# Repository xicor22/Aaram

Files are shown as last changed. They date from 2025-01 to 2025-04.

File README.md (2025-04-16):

# Aaram  
PCB design for retro fitting old switch boards with new tech to control it remotely using ESP32-C6-Mini-N1.

## Features
1. Controls 4 loads using
  - 1 Triac 
      > Note: Triac circuit has added protection for the back EMF generated by inductive load like fan.
  - 3 Relays for controlling other resistive loads
      > Try not use heavy inductive load using relays. During testing, the MCU was bugging out when load was switched.
2. Input from switches.
      - To reduce rewiring the whole switch board, directly connect the rocker switch output terminal to the input provided on the board.
      - The FULL BRIDGE RECTIFIER rectifies the AC which is sent to the quad channel opto with a 100k resistor in series for current limiting. The output from the opto is read by the ESP.
3. Fuse holder in series with the AC input for overload protection. 
4. Varistor on all AC output terminals for protection from transient spikes.
5. Added support for IR receiver and transmitter.
6. Uses DHT22 for temperature and humidity sensor.
7. ESPHome Yaml config - [Link](https://github.com/xicor22/Aaram/blob/main/ESPHome_Template.yaml)
## Schematic
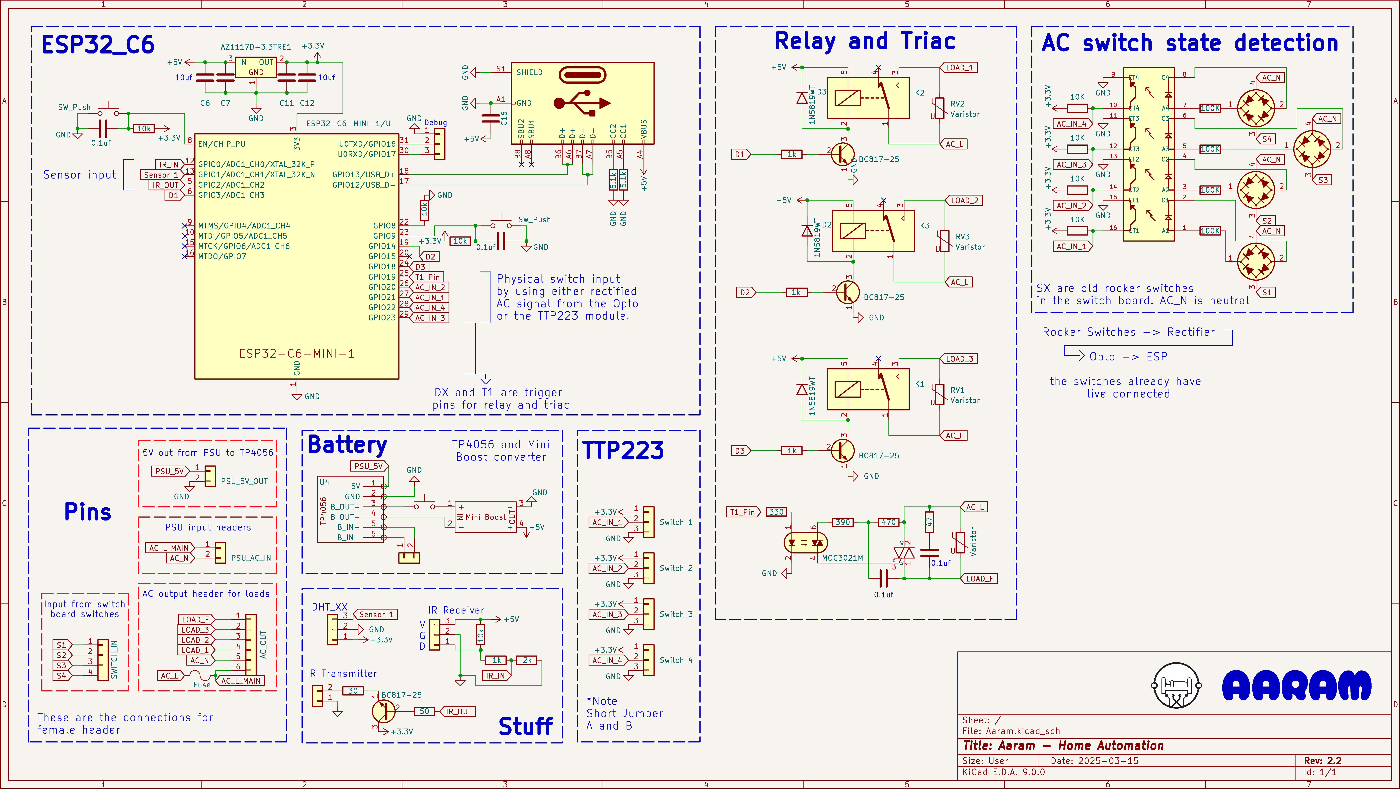
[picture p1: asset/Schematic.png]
Schematic


## Images
|View|Image|
|----|-----|
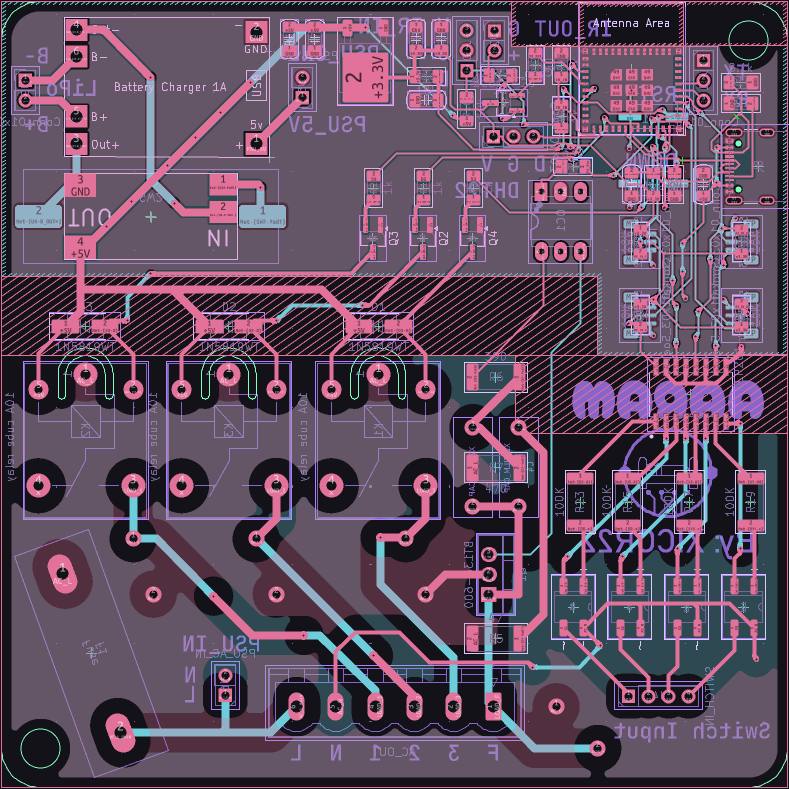
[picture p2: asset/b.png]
Both Layers
|Both Layers| |
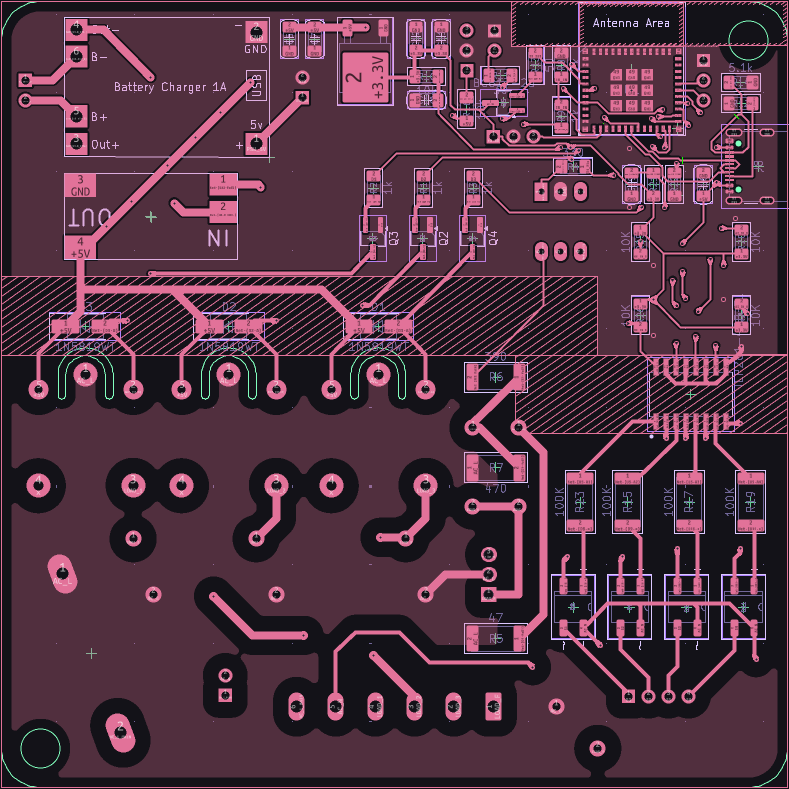
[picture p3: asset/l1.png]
Layer 1
|1<sup>st</sup> Layer| |
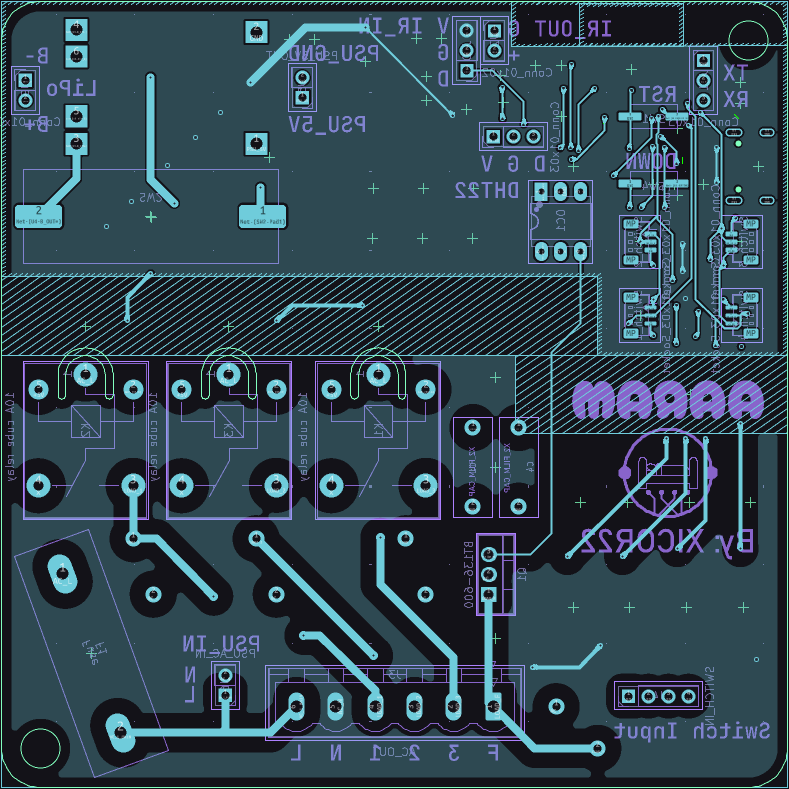
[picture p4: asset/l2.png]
Layer 2
|2<sup>nd</sup> Layer| |
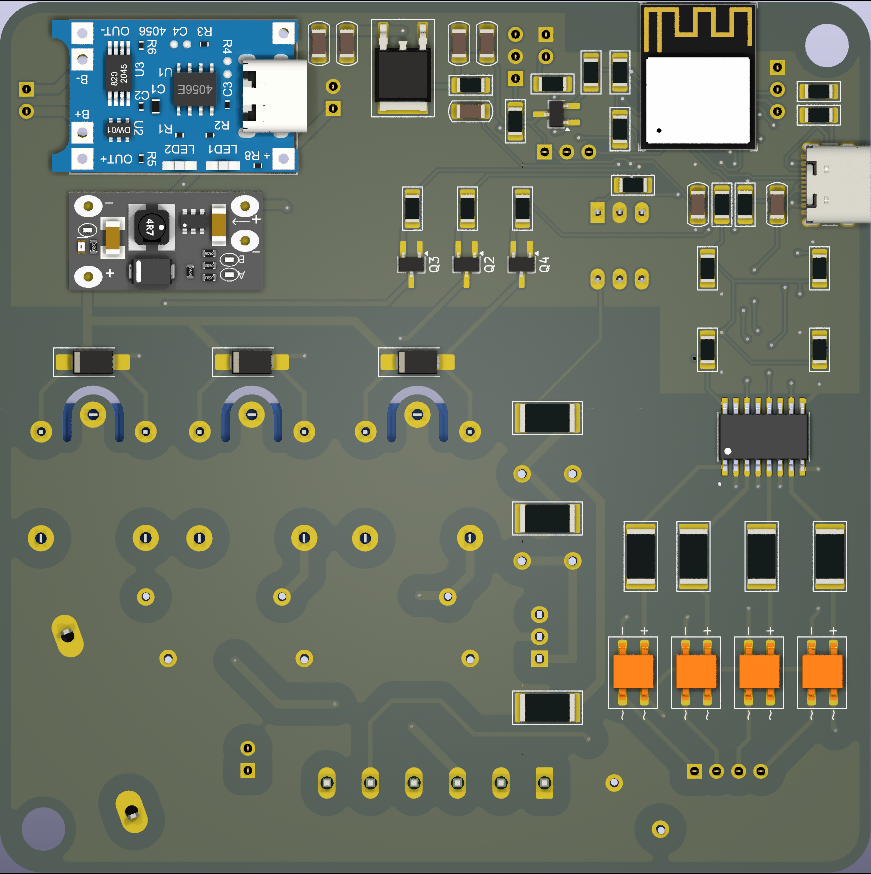
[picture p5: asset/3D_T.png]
3D Top View
|3D Top view| |
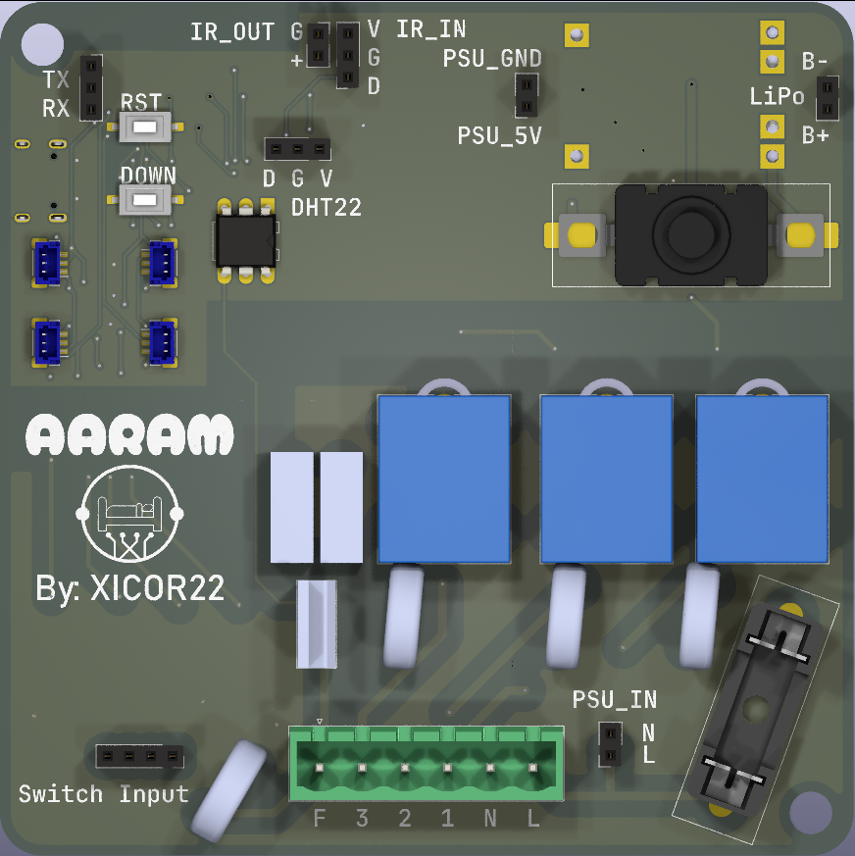
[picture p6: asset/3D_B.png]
3D Bottom View
|3D Bottom view| |

## To-Do
1. ~~Design 3D printables case for the PCB.~~ **Done**
2. Update ESPHOME yaml config.

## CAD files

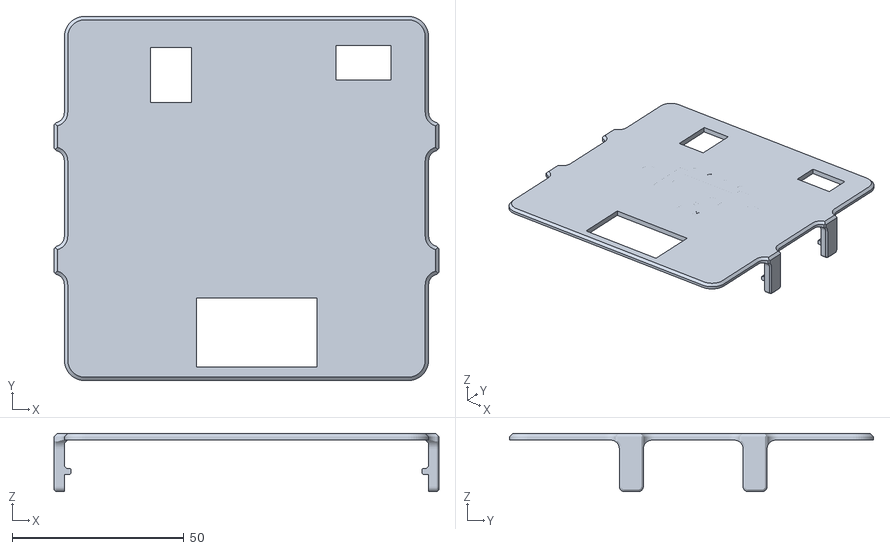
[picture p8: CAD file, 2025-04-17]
asset/Top.stl
112.0 x 106.0 x 17.0

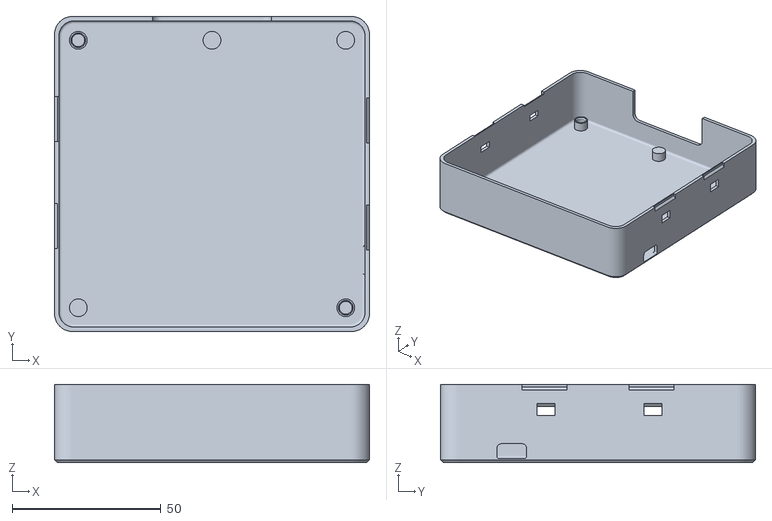
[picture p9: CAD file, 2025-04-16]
asset/Base.stl
106.0 x 106.0 x 26.4

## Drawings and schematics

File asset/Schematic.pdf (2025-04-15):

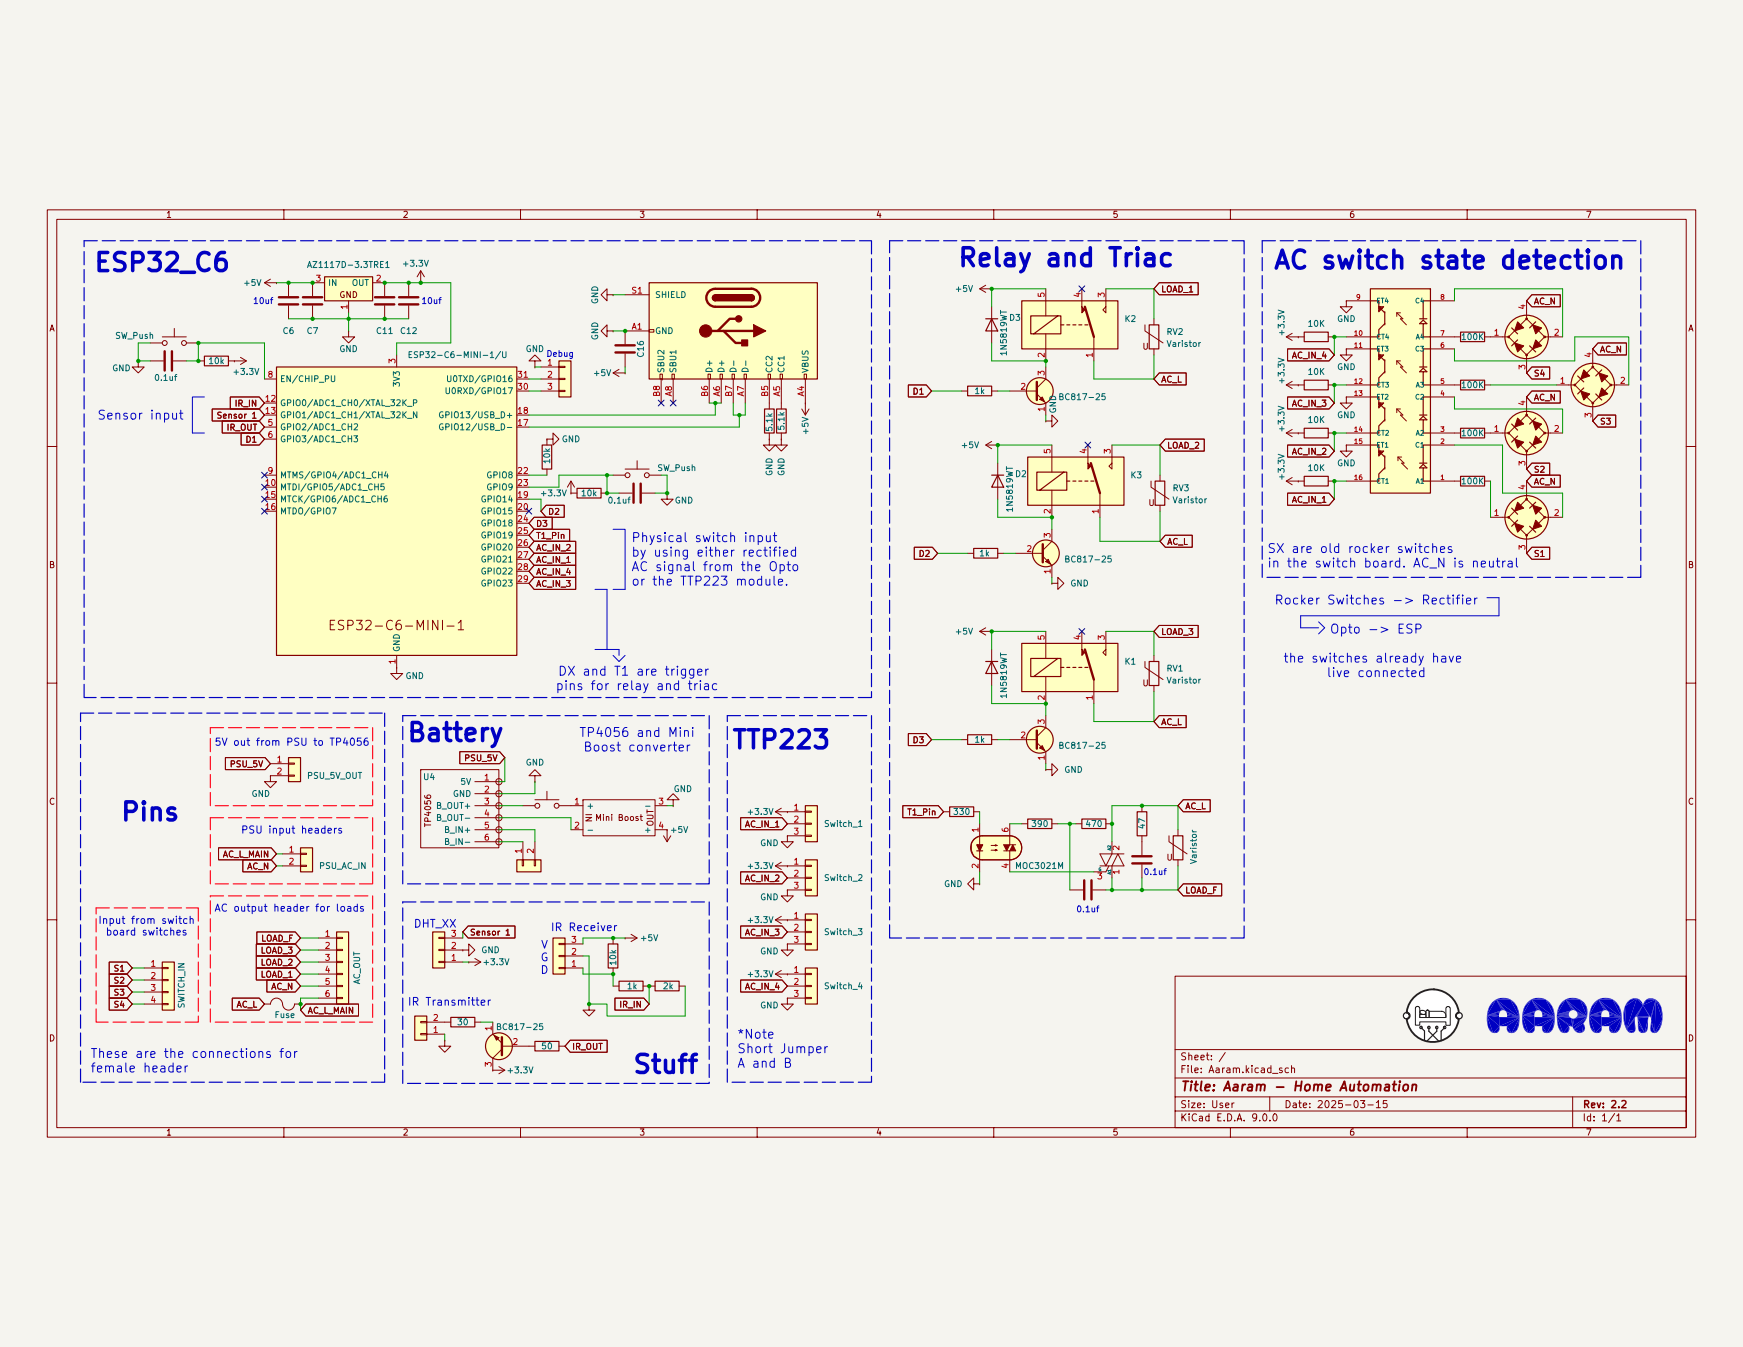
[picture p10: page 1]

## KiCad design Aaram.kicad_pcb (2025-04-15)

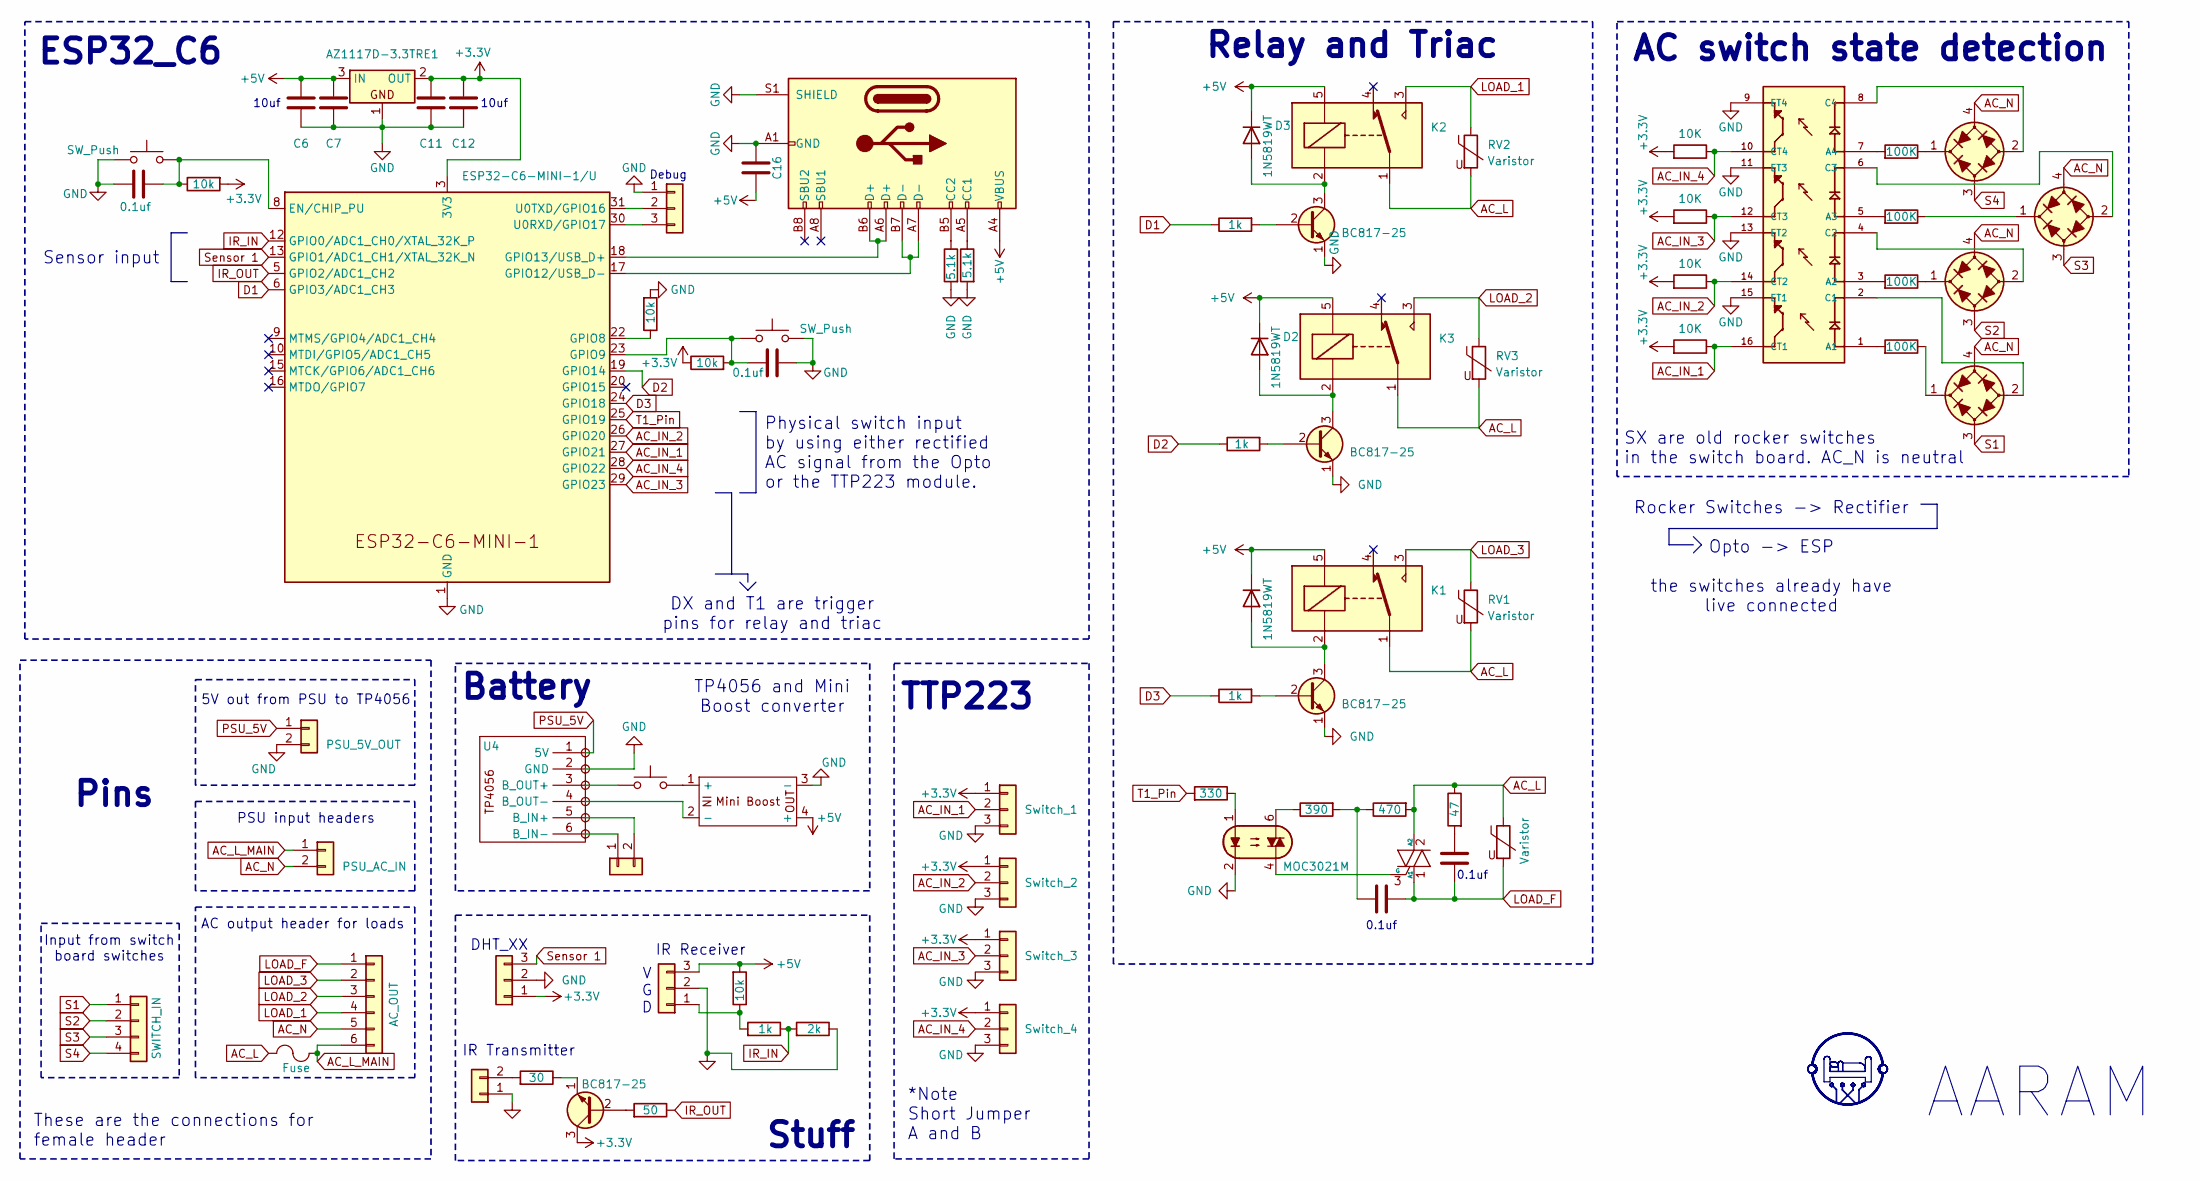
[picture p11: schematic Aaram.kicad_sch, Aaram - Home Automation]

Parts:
C1, C4: CP_Axial_L10.0mm_D4.5mm_P15.00mm; Axial_Capacitor_P10mm_W4.5mm
C6, C7, C11, C12: 10uf; C_1206_3216Metric_Pad1.42x1.75mm
C16: 1uf; C_1206_3216Metric_Pad1.42x1.75mm
C18, C19: 0.1uf; C_1206_3216Metric_Pad1.42x1.75mm
D1, D2, D3: 1N5819WT; D_SMA_Handsoldering
D8, D9, D10, D11: MB6S; Diode_Bridge_MBS
F1: Fuse; BLX-A
J1, J10, J11: Conn_01x03; PinSocket_1x03_P2.54mm_Vertical
J2, J9: Conn_01x02; PinSocket_1x02_P2.54mm_Vertical
J3: AC_OUT; 1x06_P5.00mm_D1.50mm
J4: SWITCH_IN; PinSocket_1x04_P2.54mm_Vertical
J5: PSU_5V_OUT; PinSocket_1x02_P2.54mm_Vertical
J6: PSU_AC_IN; PinSocket_1x02_P2.54mm_Vertical
J8: USB_C_Receptacle_USB2.0_16P; USB_C_Receptacle_GCT_USB4105-xx-A_16P_TopMnt_Horizontal
K1, K2, K3: 10A cube relay; Relay_SPDT_SANYOU_SRD_Series_Form_C
OC1: MOC3021M; DIP-6_W7.62mm_LongPads
Q1: BT136-600; TO-220-3_Vertical
Q2, Q3, Q4, Q5: BC817-25; TSOT-23_HandSoldering
R1, R2, R3, R9: 1k; R_1206_3216Metric_Pad1.42x1.75mm_HandSolder
R4: 330; R_1206_3216Metric_Pad1.42x1.75mm_HandSolder
R5: 47; R_2512_6332Metric_Pad1.52x3.35mm_HandSolder
R6: 390; R_2512_6332Metric_Pad1.52x3.35mm_HandSolder
R7: 470; R_2512_6332Metric_Pad1.52x3.35mm_HandSolder
R8: 2k; R_1206_3216Metric_Pad1.42x1.75mm_HandSolder
R10, R16, R21, R22: 10k; R_1206_3216Metric_Pad1.42x1.75mm_HandSolder
R11: 30; R_1206_3216Metric_Pad1.42x1.75mm_HandSolder
R12, R14: 5.1k; R_1206_3216Metric_Pad1.42x1.75mm_HandSolder
R13: 50; R_1206_3216Metric_Pad1.42x1.75mm_HandSolder
R15, R17, R19, R23: 100K; R_2512_6332Metric_Pad1.52x3.35mm_HandSolder
R20, R25, R26, R27: 10K; R_1206_3216Metric_Pad1.42x1.75mm_HandSolder
RV1, RV2, RV3, RV4: Varistor; Varistor_10D431K
SW1, SW4: SW_Push; Tactile switch 6x3
SW2: SW_Push; SMD Tactile switch
Switch_1, Switch_2, Switch_3, Switch_4: Conn_01x03_Socket; JST_SH_BM03B-SRSS-TB_1x03-1MP_P1.00mm_Vertical
U1: ESP32-C6-MINI-1/U; ESP32-C6-MINI-1
U2: AZ1117D-3.3TRE1; TO-252-2
U3: Mini_Boost
U4: TP4056-18650
U5: TLP281-4GB_F_; SOP127P780X200-16N

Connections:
+3.3V: C11.2, C12.2, J1.1, Q5.3 (C), R10.1, R20.1, R21.2, R25.1, R26.1, R27.1, Switch_1.1, Switch_2.1, Switch_3.1, Switch_4.1, U1.3 (3V3), U2.2 (OUT)
+5V: C6.2, C7.2, C16.1, D1.1 (K), D2.1 (K), D3.1 (K), J8.A4 (VBUS), J8.A9 (VBUS), J8.B4 (VBUS), J8.B9 (VBUS), J10.3, K1.5, K2.5, K3.5, R16.1, U2.3 (IN), U3.4 (+)
AC_IN_1: R26.2, Switch_1.2, U1.27 (GPIO21), U5.16 (CT1)
AC_IN_2: R25.2, Switch_2.2, U1.26 (GPIO20), U5.14 (CT2)
AC_IN_3: R20.2, Switch_3.2, U1.29 (GPIO23), U5.12 (CT3)
AC_IN_4: R27.2, Switch_4.2, U1.28 (GPIO22), U5.10 (CT4)
AC_L: F1.1, K1.1, K2.1, K3.1, Q1.2 (A2), R5.2, R7.1, RV1.2, RV2.2, RV3.2, RV4.1
AC_L_MAIN: F1.2, J3.6, J6.1
AC_N: D8.4 (2), D9.4 (2), D10.4 (2), D11.4 (2), J3.5, J6.2
D1: R2.2, U1.6 (GPIO3/ADC1_CH3)
D2: R1.2, U1.19 (GPIO14)
D3: R3.2, U1.24 (GPIO18)
GND: C6.1, C7.1, C11.1, C12.1, C16.2, C18.1, C19.1, J1.2, J2.1, J5.2, J8.A1 (GND), J8.A12 (GND), J8.B1 (GND), J8.B12 (GND), J8.S1 (SHIELD), J10.2, J11.1, OC1.2, Q2.1 (E), Q3.1 (E), Q4.1 (E), R8.2, R12.1, R14.1, R22.1, SW1.1, SW4.1, Switch_1.3, Switch_2.3, Switch_3.3, Switch_4.3, U1.1 (GND), U1.2 (GND), U1.11 (GND), U1.14 (GND), U1.36 (GND), U1.37 (GND), U1.38 (GND), U1.39 (GND), U1.40 (GND), U1.41 (GND), U1.42 (GND), U1.43 (GND), U1.44 (GND), U1.45 (GND), U1.46 (GND), U1.47 (GND), U1.48 (GND), U1.49 (GND), U1.50 (GND), U1.51 (GND), U1.52 (GND), U1.53 (GND), U2.1, U3.3 (-), U4.2 (GND), U5.9 (ET4), U5.11 (ET3), U5.13 (ET2), U5.15 (ET1)
IR_IN: R8.1, R9.2, U1.12 (GPIO0/ADC1_CH0/XTAL_32K_P)
IR_OUT: R13.2, U1.5 (GPIO2/ADC1_CH2)
LOAD_1: J3.4, K2.3, RV2.1
LOAD_2: J3.3, K3.3, RV3.1
LOAD_3: J3.2, K1.3, RV1.1
LOAD_F: C1.2, C4.2, J3.1, Q1.1 (A1), RV4.2
unnamed: C1.1, R6.1, R7.2
unnamed: C4.1, R5.1
unnamed: D1.2 (A), K1.2, Q4.3 (C)
unnamed: D2.2 (A), K3.2, Q2.3 (C)
unnamed: D3.2 (A), K2.2, Q3.3 (C)
unnamed: D8.1 (+), R23.2
unnamed: D8.2 (-), U5.2 (C1)
unnamed: D9.1 (+), R15.2
unnamed: D9.2 (-), U5.4 (C2)
unnamed: D10.1 (+), R17.2
unnamed: D10.2 (-), U5.6 (C3)
unnamed: D11.1 (+), R19.2
unnamed: D11.2 (-), U5.8 (C4)
unnamed: J2.2, R11.1
unnamed: J8.A5 (CC1), R12.2
unnamed: J8.B5 (CC2), R14.2
unnamed: J9.1, U4.6 (B_IN-)
unnamed: J9.2, U4.5 (B_IN+)
unnamed: J10.1, R9.1, R16.2
unnamed: J11.2, U1.31 (U0TXD/GPIO16)
unnamed: J11.3, U1.30 (U0RXD/GPIO17)
unnamed: OC1.1, R4.2
unnamed: OC1.6, R6.2
unnamed: OC1.4, Q1.3 (G)
unnamed: Q2.2 (B), R1.1
unnamed: Q3.2 (B), R2.1
unnamed: Q4.2 (B), R3.1
unnamed: Q5.2 (B), R13.1
unnamed: Q5.1 (E), R11.2
unnamed: SW2.1, U3.1 (+)
unnamed: C18.2, R10.2, SW1.2, U1.8 (EN/CHIP_PU)
unnamed: R22.2, U1.22 (GPIO8)
unnamed: C19.2, R21.1, SW4.2, U1.23 (GPIO9)
unnamed: J8.A7 (D-), J8.B7 (D-), U1.17 (GPIO12/USB_D-)
unnamed: J8.A6 (D+), J8.B6 (D+), U1.18 (GPIO13/USB_D+)
unnamed: SW2.2, U4.3 (B_OUT+)
unnamed: U3.2 (-), U4.4 (B_OUT-)
unnamed: R23.1, U5.1 (A1)
unnamed: R15.1, U5.3 (A2)
unnamed: R17.1, U5.5 (A3)
unnamed: R19.1, U5.7 (A4)
PSU_5V: J5.1, U4.1 (5V)
S1: D8.3 (1), J4.1
S2: D9.3 (1), J4.2
S3: D10.3 (1), J4.3
S4: D11.3 (1), J4.4
Sensor 1: J1.3, U1.13 (GPIO1/ADC1_CH1/XTAL_32K_N)
T1_Pin: R4.1, U1.25 (GPIO19)

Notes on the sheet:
IR Transmitter
0.1uf
Sensor input
Input from switch board switches
Physical switch input by using either rectified AC signal from the Opto or the TTP223 module.
5V out from PSU to TP4056
AC switch state detection
TP4056 and Mini Boost converter
Relay and Triac
10uf
Debug
Pins
TTP223
Rocker Switches -> Rectifier Opto -> ESP the switches already have live connected
V G D
PSU input headers
AARAM
Battery
IR Receiver
ESP32_C6
DHT_XX
Stuff
*Note Short Jumper A and B
These are the connections for female header
AC output header for loads
DX and T1 are trigger pins for relay and triac
SX are old rocker switches in the switch board. AC_N is neutral

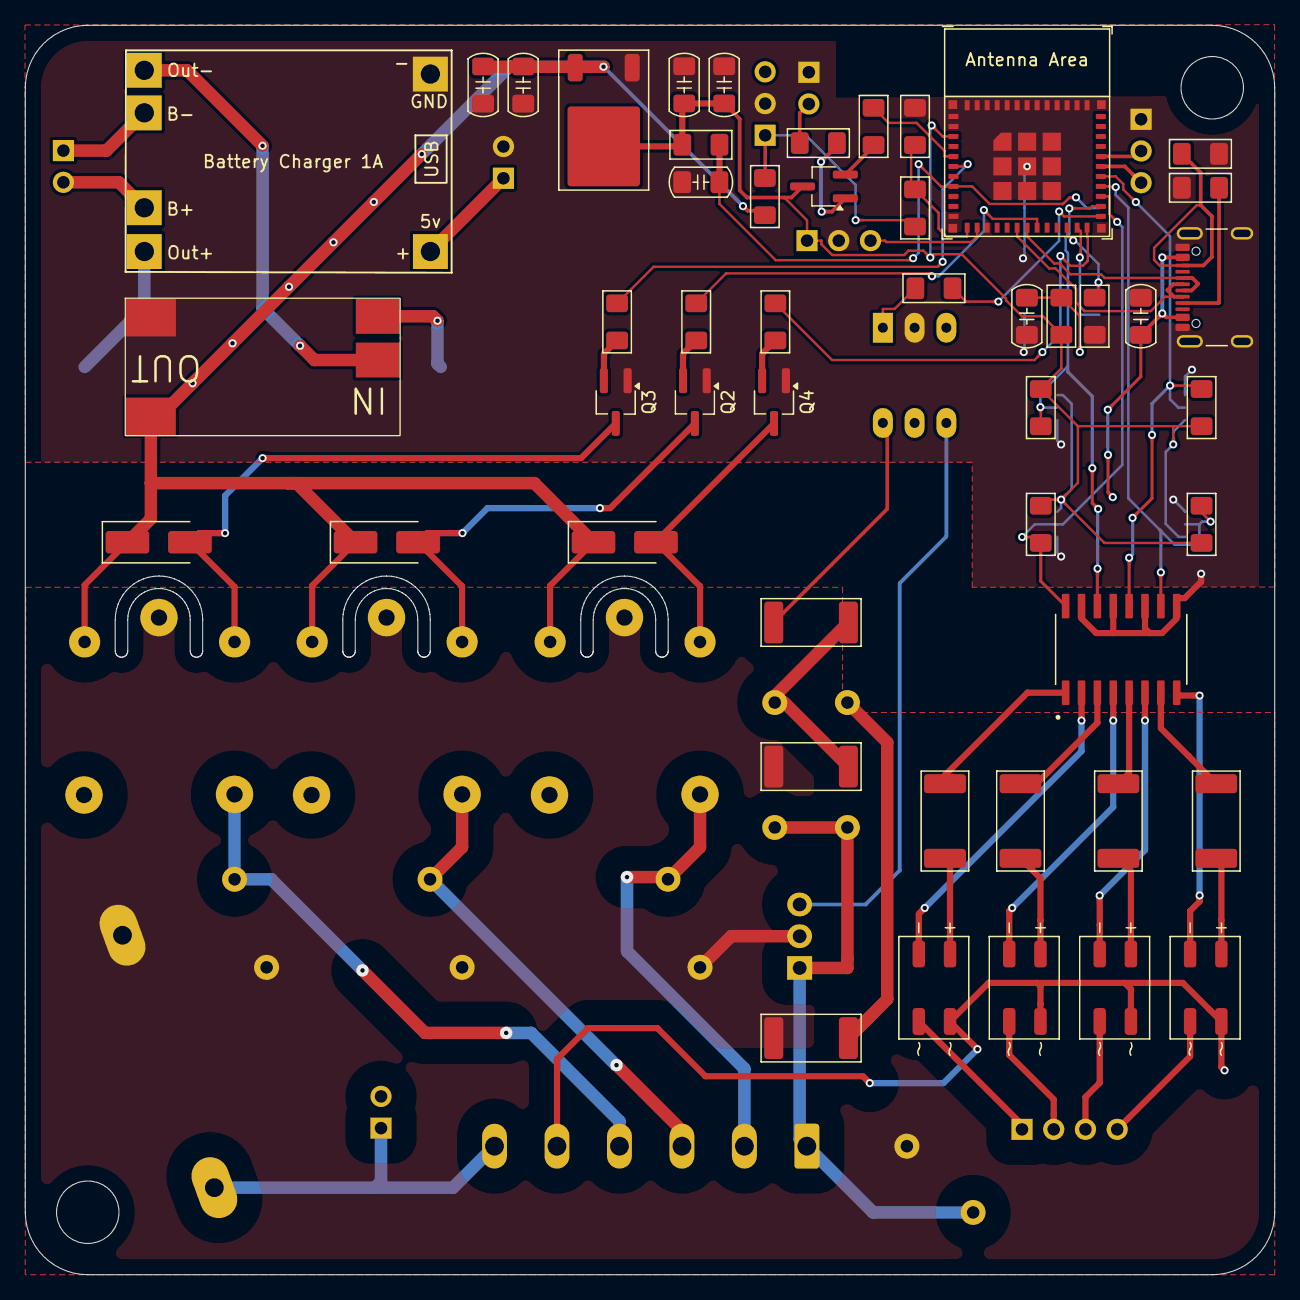
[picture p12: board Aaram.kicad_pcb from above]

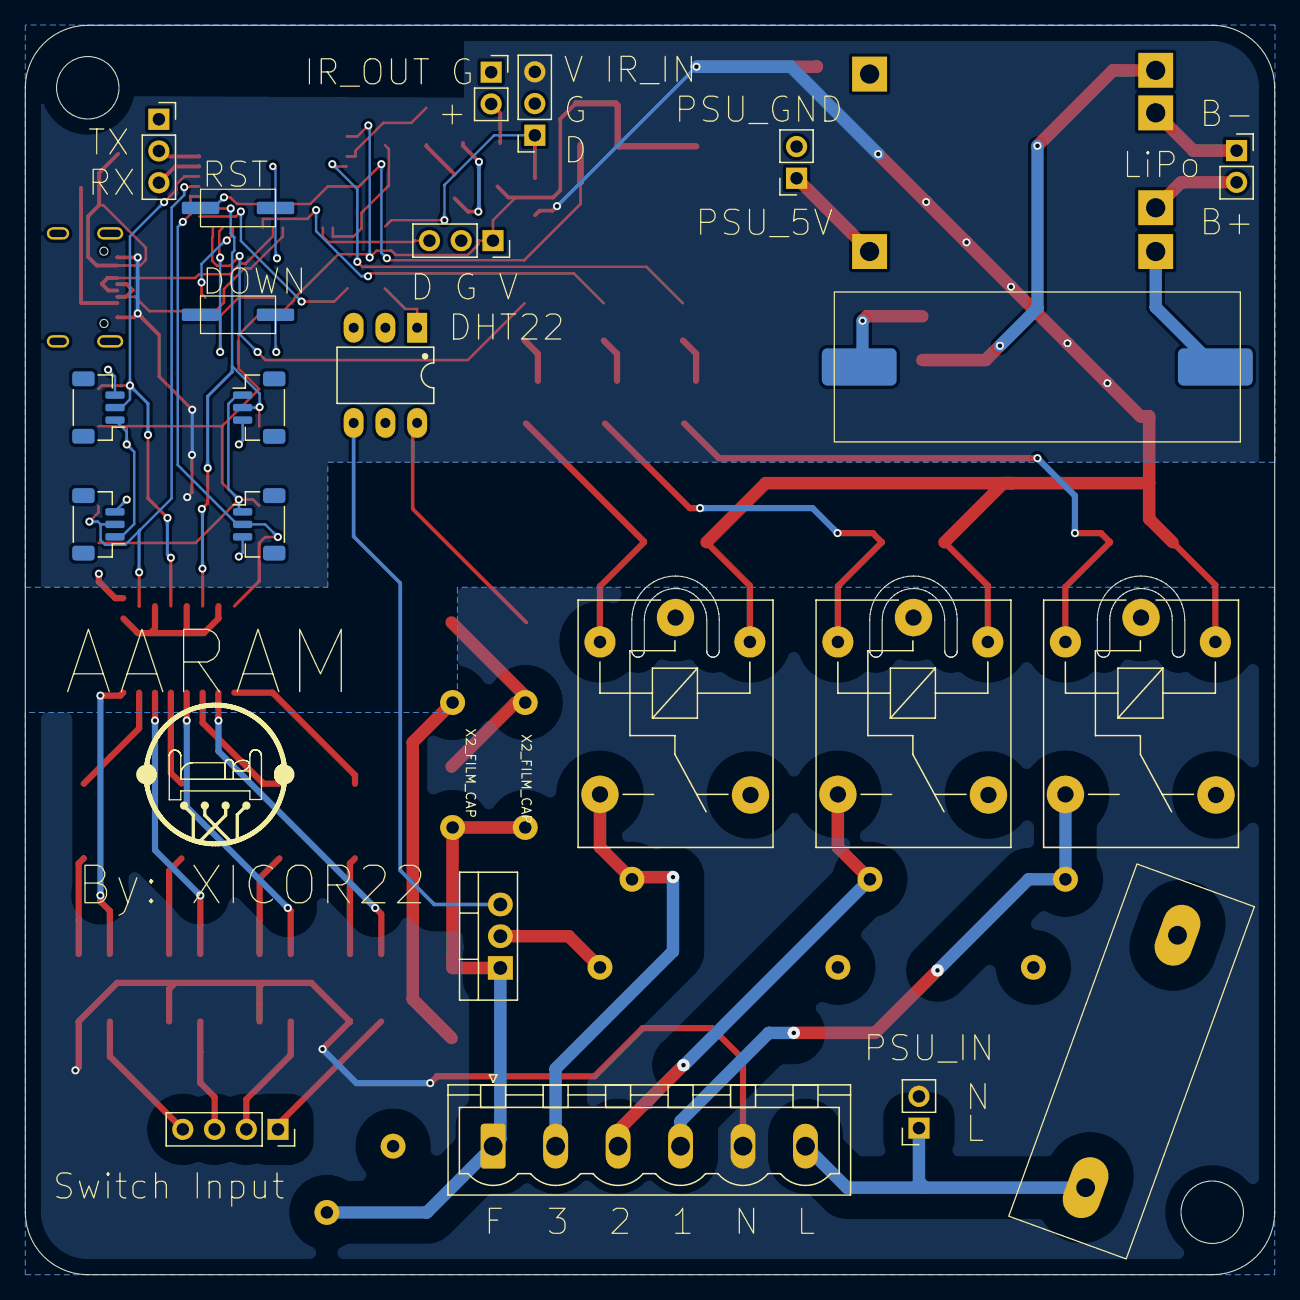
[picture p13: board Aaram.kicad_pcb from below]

Board: 2 copper layers, 100.0 x 100.0 mm, 77 parts (28 on the bottom side), 67 nets.

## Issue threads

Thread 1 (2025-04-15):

Issue with ZMCT103C and switch detection

xicor22, 2025-04-15:
After PCB fabrication, AC switch detection using half bridge rectification didn't work at all.
Due to not enough support for the ZMCT103C current sensor, This didn't work reliably for me.

xicor22, 2025-04-15:
Fixed in #2

Closed 2025-04-15.

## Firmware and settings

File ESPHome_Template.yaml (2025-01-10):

substitutions:
  name: balcony-32s
  friendly_name: Balcony
  key: !secret MCU32S-Balcony_key
  ota: !secret MCU32S-Balcony_ota
  wifipass: !secret ap_pass

esphome:
  name: ${name}
  friendly_name: ${friendly_name}
  min_version: 2024.6.0
  name_add_mac_suffix: false
  project:
    name: esphome.web
    version: '1.0'

esp32:
  board: nodemcu-32s
  framework:
    type: arduino
    version: recommended

# Enable logging
logger:
  baud_rate: 0

dashboard_import:
  package_import_url: github://esphome/example-configs/esphome-web/esp32.yaml@main
  import_full_config: true

preferences:
  flash_write_interval: 2min

web_server:

esp32_improv:
  authorizer: none

# Enable Home Assistant API
api:
  encryption:
    key: ${key}

ota:
  - platform: esphome
    password: ${ota}

wifi:
  networks:
    - ssid: !secret wifi_ssid
      password: !secret wifi_password
    - ssid: !secret wifi_ssid_1
      password: !secret wifi_password_1
  # Enable fallback hotspot (captive portal) in case wifi connection fails
  ap:
    ssid: ${name}
    password: ${wifipass}

captive_portal:

switch:
  - platform: gpio
    pin: 21
    name: "Light"
    id: light
    inverted: no
    restore_mode: RESTORE_DEFAULT_OFF

  - platform: gpio
    pin: 13
    name: "Fan"
    id: fan
    inverted: no
    restore_mode: RESTORE_DEFAULT_OFF

  - platform: gpio
    pin: 23
    name: "Right Socket"
    id: right
    inverted: no
    restore_mode: RESTORE_DEFAULT_OFF
  
  - platform: gpio
    pin: 22
    name: "Left Socket"
    id: left
    inverted: no
    restore_mode: RESTORE_DEFAULT_OFF

binary_sensor:
#Right Socket
  - platform: gpio
    name: "Switch1"
    id: S1
    pin:
      number: 16
      inverted: True
      mode: 
        input: True
        pullup: True
    filters:
      - delayed_on: 500ms
    on_state:
      then:
        - if:
            condition:
              - binary_sensor.is_on: S1
            then:
              - switch.turn_on: right
            else:
              - switch.turn_off: right


#Left Socket
  - platform: gpio
    name: "Switch2"
    id: S2
    pin:
      number: 17
      inverted: True
      mode: 
        input: True
        pullup: True
    filters:
      - delayed_on: 500ms
    on_state:
      then:
        - if:
            condition:
              - binary_sensor.is_on: S2
            then:
              - switch.turn_on: left
            else:
              - switch.turn_off: left

#Fan
  - platform: gpio
    name: "Switch3"
    id: S3
    pin:
      number: 18
      inverted: True
      mode: 
        input: True
        pullup: True
    filters:
      - delayed_on: 500ms
    on_state:
      then:
        - if:
            condition:
              - binary_sensor.is_on: S3
            then:
              - switch.turn_on: fan
            else:
              - switch.turn_off: fan

#Light
  - platform: gpio
    name: "Switch4"
    id: S4
    pin:
      number: 19
      inverted: True
      mode: 
        input: True
        pullup: True
    filters:
      - delayed_on: 500ms
    on_state:
      then:
        - if:
            condition:
              - binary_sensor.is_on: S4
            then:
              - switch.turn_on: light
            else:
              - switch.turn_off: light

button:
  - platform: restart
    name: "Balcony Restart"

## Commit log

2024-12-19 Added the files
    [Aaram.kicad_pcb, Aaram.kicad_sch]
2024-12-19 Added schematics
2024-12-20 Added 5v connection to relays
    [Aaram.kicad_pcb, Aaram.kicad_sch]
2024-12-20 Fixed edge cut layer
    [Aaram.kicad_pcb]
2024-12-23 Fixed unconnected tracks of triac
    [Aaram.kicad_pcb]
2025-01-10 Updated Silkscreen and connections
    Moved the fan control from GPIO4 to GPIO 13, made changes to the silkscreen and redid some of the tracks for better layout.
    [Aaram.kicad_pcb, Aaram.kicad_sch]
2025-01-14 Component update
    Changed most of the components to use SMD form factor, updated clearance between components in the AC zone and updated the tracks.
    [Aaram.kicad_pcb, Aaram.kicad_sch]
2025-04-15 Major Update (#2)
    * Updated mostly everything
    * Big Update
    * Major Update
    - Removed All 3D related files for now.
    - Updated the Schematics and PCB
    - Updated the assets
    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
    [Aaram.kicad_pcb, Aaram.kicad_sch]
2025-04-16 3D stuff
    Added PCB step file, Designed a case for the pcb
    [Base.stl, Top.stl]
2025-04-17 Updated enclosure lid
    [Top.stl]
